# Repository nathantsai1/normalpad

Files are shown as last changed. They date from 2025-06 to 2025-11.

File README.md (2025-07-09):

# NormalPad

*Note: this is a hackboard, not a hackpad
## What is this?
This is a 75% keyboard inspired by the [Keychron Q1 Custom Keyboard](https://www.keychron.com/products/keychron-q1?srsltid=AfmBOorYcrgbMnQshTxcVkn31a3YPq6My79lAXlqjA35xHALWIpRg0Ld). It consists of 82 keys, hot-swappable switches a 3D printable case, and stabilizers. The bottom half is split in half to make it easier to sand

## Quick overview of repo
+ cad
    1. full_keyboard.stl
+ firmware
    1. normalPad.ino
+ pcb
    1. hackpad_v2.kicad_pcb
    2. hackpad_v2.kicad_prl
    3. hackpad_v2.kicad_pro
    4. hackpad_v2.kicad_sch
+ production
    + cad(stl)
        1. plate.stl
        2. upper_ex.stl
        3. bottom.stl
    1. normalPad.ino
    2. gerbers-zip.zip
+ src
    1. angle_bottom.png
    2. assembled_bottom.png
    3. bottom.png
    4. diagram.png
    5. pcb.png
    6. plate.png
    7. schem.png
    8. side_short.png
    9. side_long.png
    10. together.png
    11. top_plate.png
+ README.md
+ bom.csv
+ JOURNAL.md

*The more important files are contained in the production folder, README, and bom(in a ccsv file and at the end of this page)
## Why did I make this
I primarily started this for [HackPad v2](https://hackpad.hackclub.com/keyboard). However, during the process of making this, I learned more about the different types of switches, stabilizers, splitting up CAD designs into multiple parts, and all the parts of the keyboard. I learned a little bit more about the [Arduino Keyboard library](https://docs.arduino.cc/language-reference/en/functions/usb/Keyboard/), how to write relatively efficient code, and organize my pcb schematic and pcb in a larger scale than what I previously learned. As I had taken a break for a few months from my original keyboard design, I had stopped 

## Pictures of my design:
### Schematic:
<b>My diagram, which depicts the row and column numbers</b>

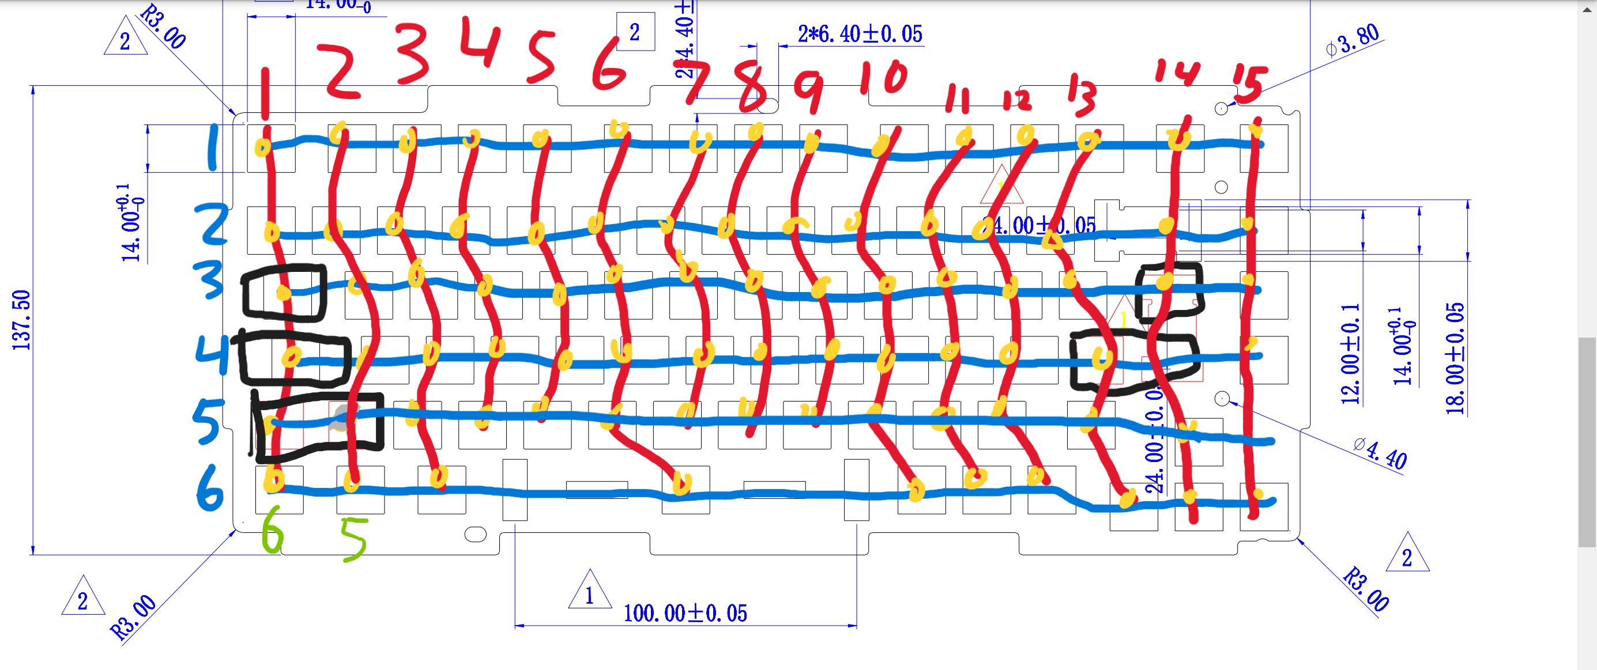
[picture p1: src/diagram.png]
diagram


<b>The schematic for the pcb, relatively organized in the order wanted</b>

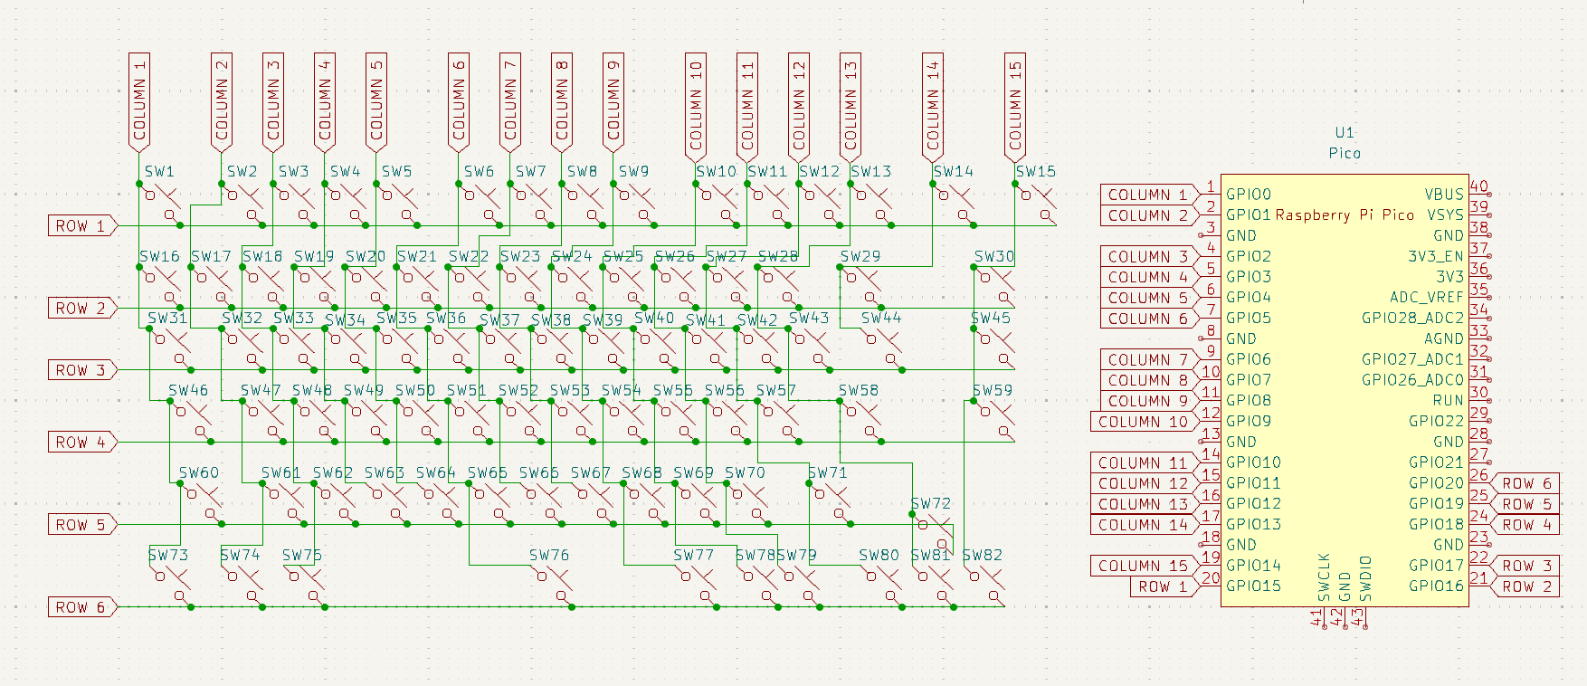
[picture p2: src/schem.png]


### PCB
<b>My PCB</b>

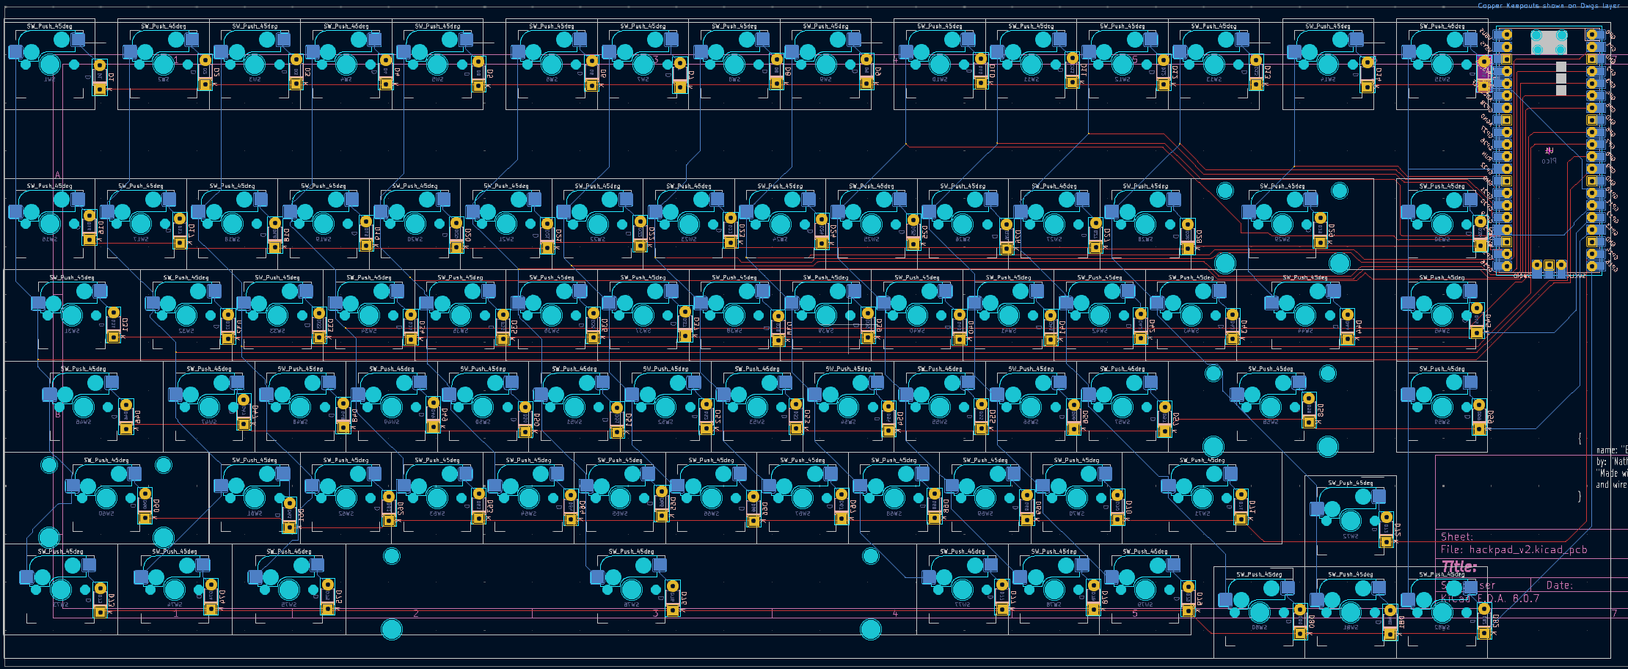
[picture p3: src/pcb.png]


<b>PCB back</b>

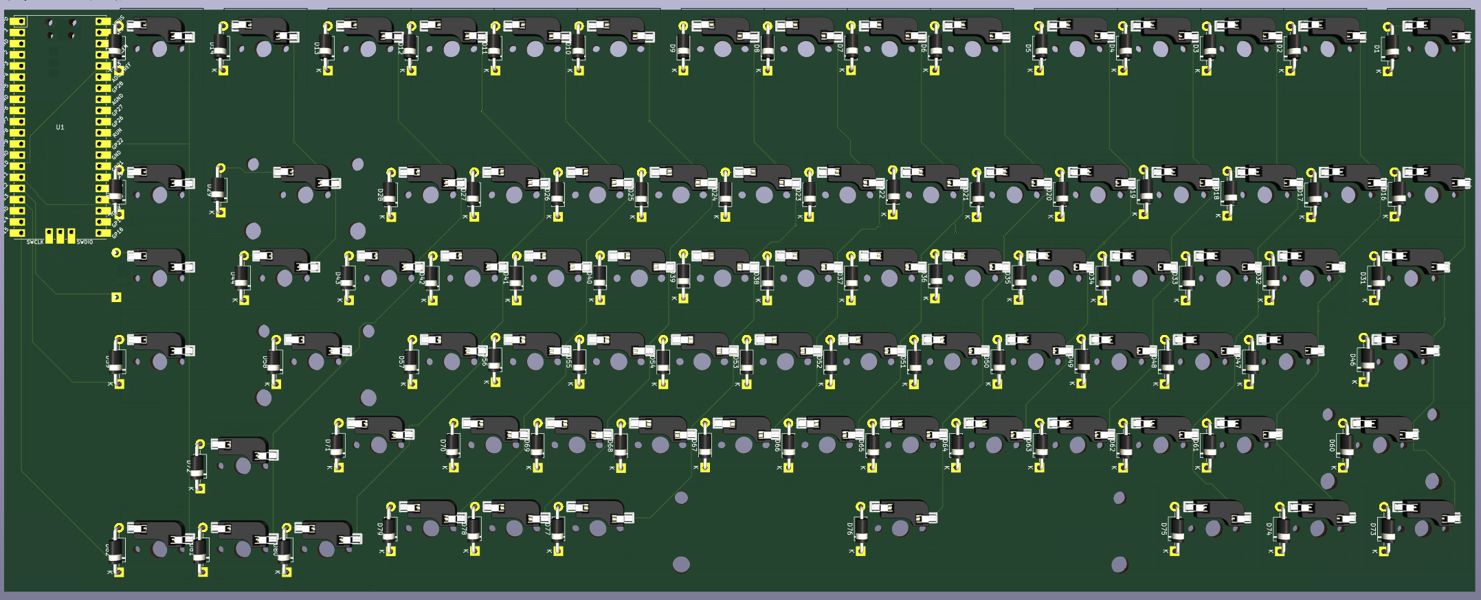
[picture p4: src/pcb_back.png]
pcb back


<b>PCB front (w/key switch side)</b>

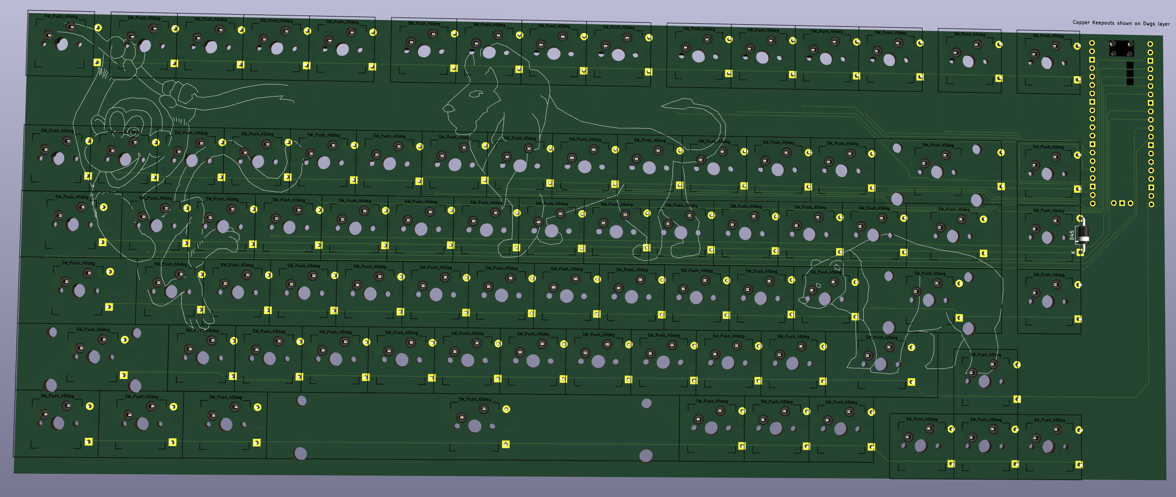
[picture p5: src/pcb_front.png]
pcb front


### CAD Case(Disassembled)
From top to bottom 

<b>Top plate</b>

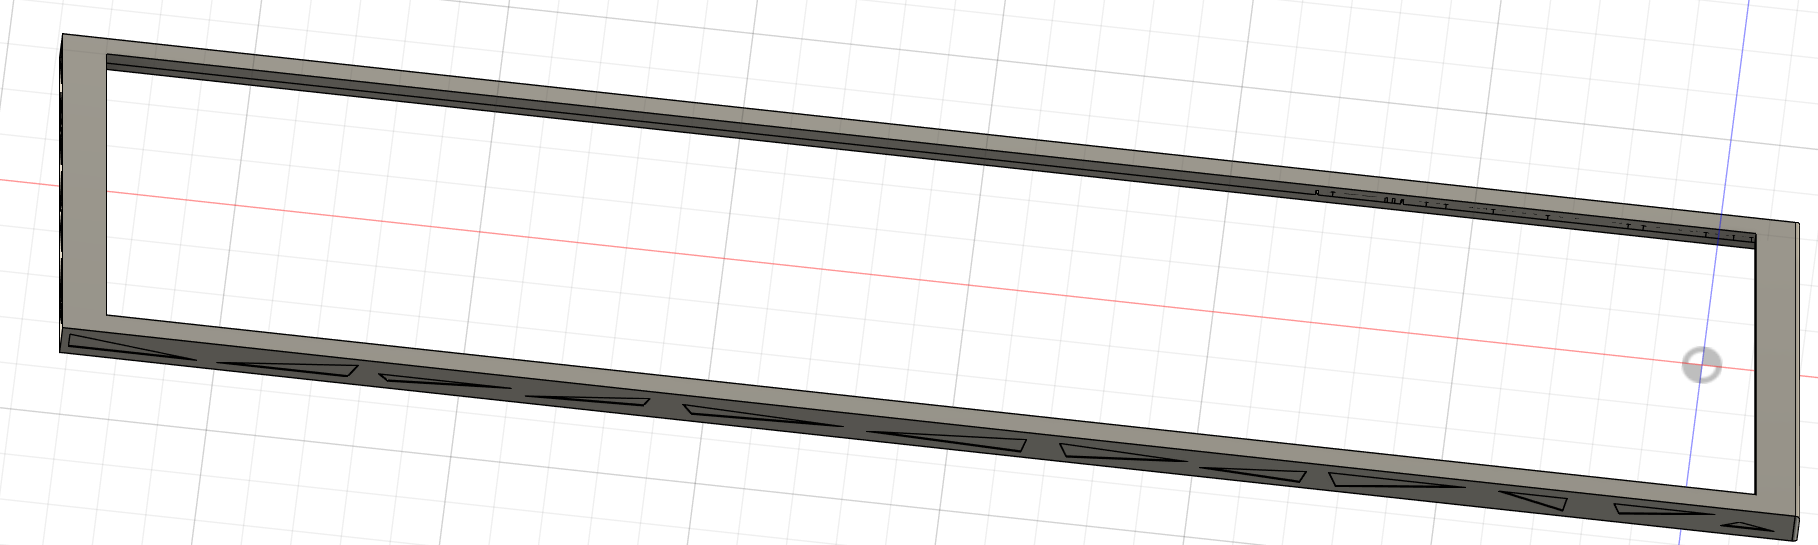
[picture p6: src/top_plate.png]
Top Plate


<b>Plate</b>

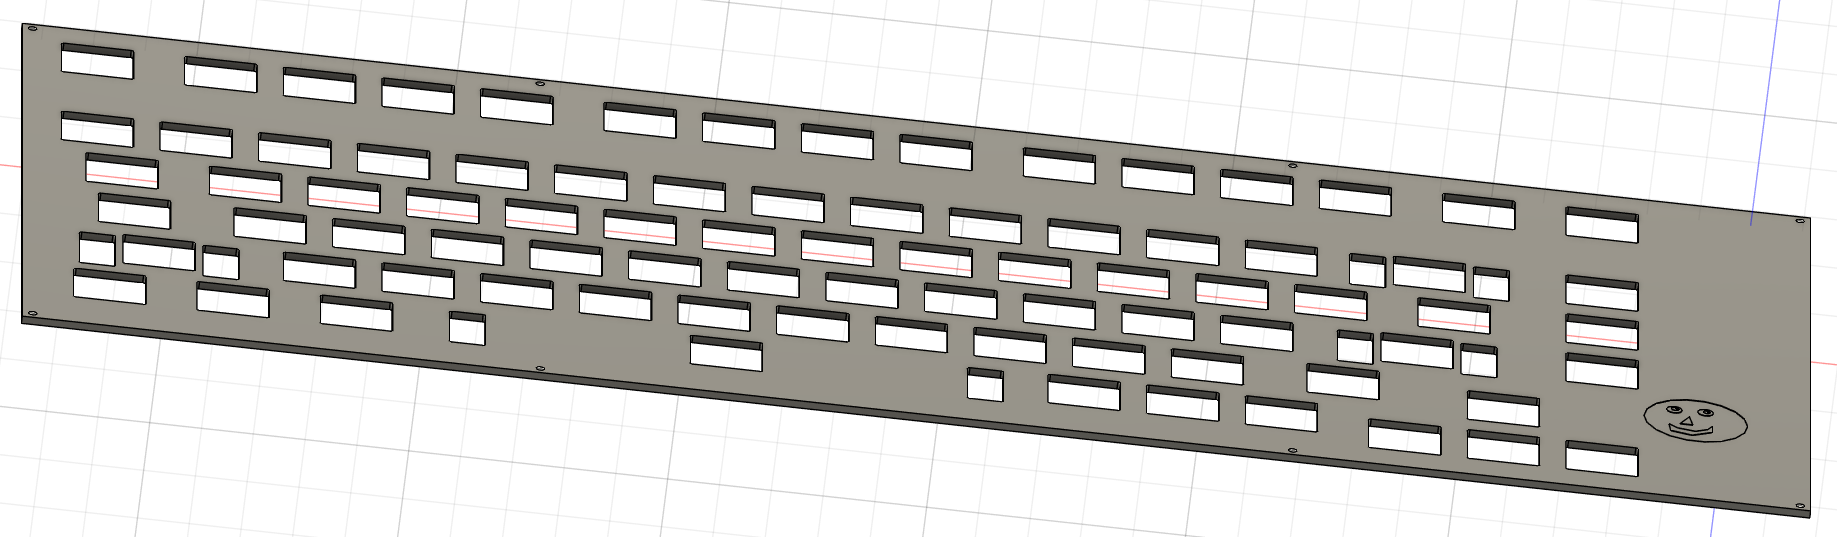
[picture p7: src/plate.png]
Plate


<b>Bottom</b>

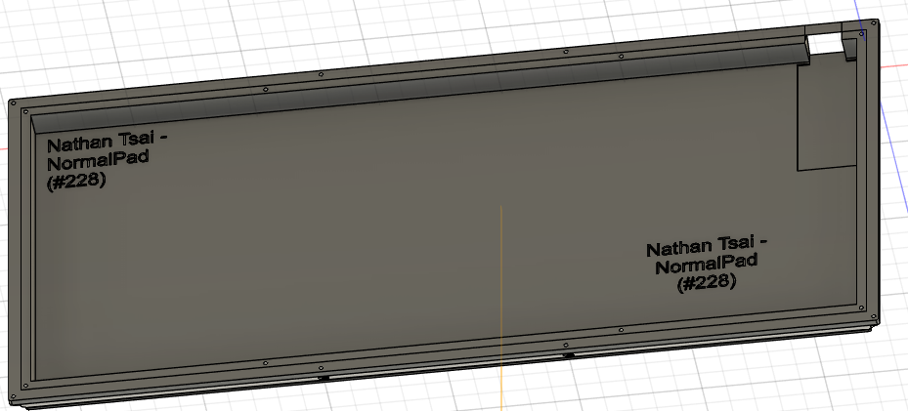
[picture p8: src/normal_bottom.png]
Bottom


### CAD case(relatively assembled)

<b>Assembled case</b>

Bottom assembled
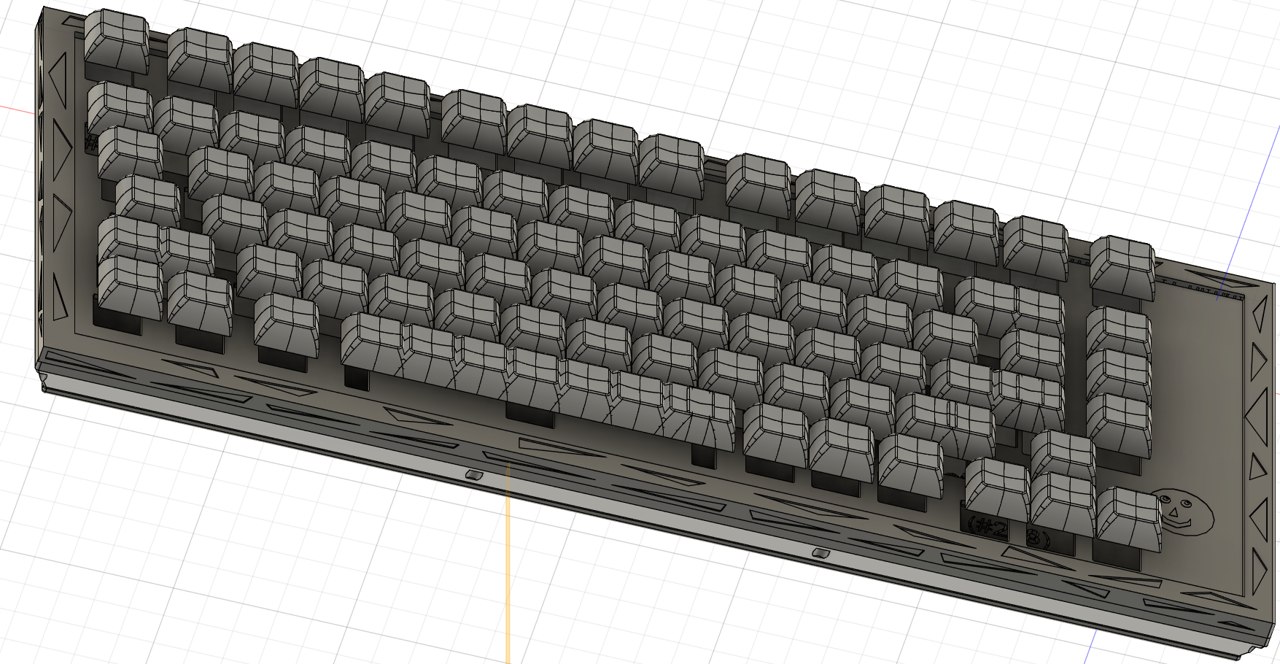
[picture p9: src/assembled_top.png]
Top assembled


<b>Side analysis of case</b>

side_long
side_short

<b>sketch of designsadded to project</b>
in order: back case, front case, front pcb

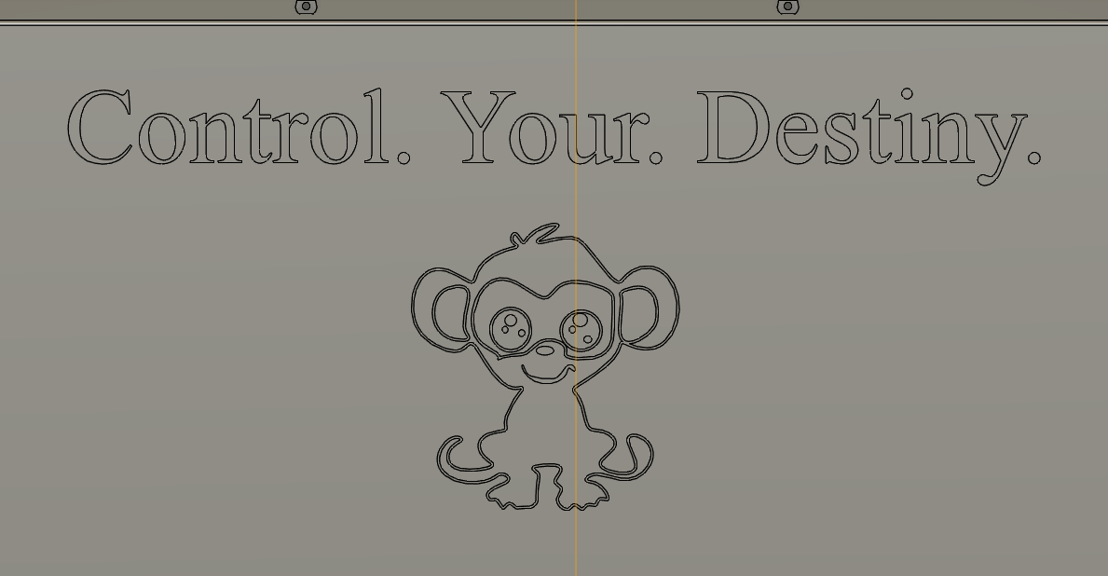
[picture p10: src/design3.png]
back_design

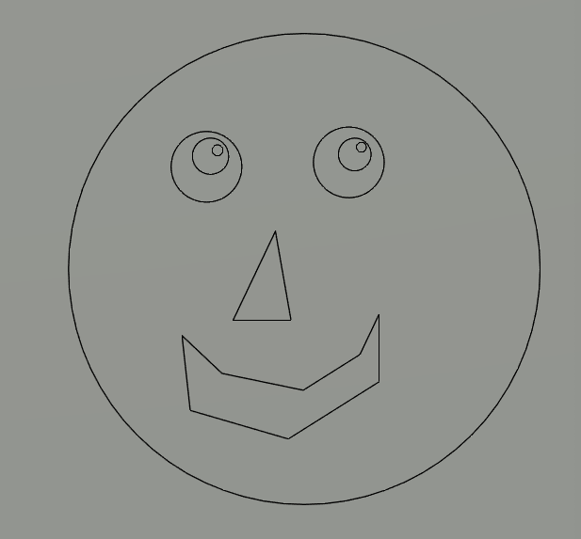
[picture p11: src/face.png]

back_design

## Bill of Materials
Also see [here](./BOM.csv)
|mfg name|	 Description|	 Price|	shipping|	total|	notes|
| ---| ---| ---| ---| ---| ---|
|ALIEXPRESS|	 [keycap set](https://www.aliexpress.us/item/3256803996370867.html)|	 9.23|	0|	 9.23| |
|ALIEXPRESS|	 [keyswitch(90)](https://www.aliexpress.us/item/3256807160745636.html)|	 25.17|	0|	 25.17| |
|ALIEXPRESS|	 taxes|	 0|	0|	 0| |
| | | | | | |
|JLCPCB|	 pcb|	 20.9|	17.13|	 38.03| |
| | | | | | |
|MECHANICAL KEYBOARD| [hot swap(90)](https://mechanicalkeyboards.com/products/kailh-switch-hot-swap-socket)|	 9.9| 	5.8|	 15.15| |
|MECHANIAL KEYBOARDS| [stabilizer](https://mechanicalkeyboards.com/products/durock-v3-pcb-mount-screw-in-stabilizer-tkl-kit)|	 15|	 6.27|	 21.27| |
| | | | | | |
|DIGIKEY|	 [Raspberry pi pico w/o header](https://www.digikey.com/en/products/detail/raspberry-pi/SC0915/13624793)|	 5|  	0|	 5| |
|DIGIKEY|	 [pin header 1x40](https://www.digikey.com/en/products/detail/amphenol-cs-commercial-products/G800W268018EU/17083164)|	 0.8|	|	 0.8| |
|DIGIKEY|	 [bolts(2Mx0.4 - 8mm*18)](https://www.digikey.com/en/products/detail/essentra-components/50M020040P008/11639927)|	1.76|	0|	 1.76| |
|DIGIKEY|	 [diode(84)](https://www.digikey.com/en/products/detail/comchip-technology/1N4001-G/1979654)|	 4.54|	0|	 4.54| |
|DIGIKEY|	 total(tariff+tax, shipping)|	 1.57|	4.99|	 6.56| |
|CAD CASE|	 cad case|	 |	|	 5.51| |
Total (with case and PCB): 133.02
Total (without case and PCB) 89.48
*PRICES IN USD

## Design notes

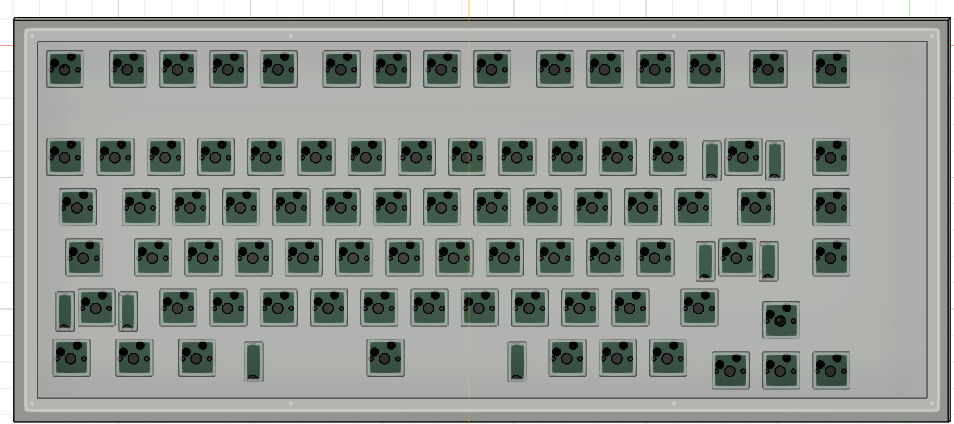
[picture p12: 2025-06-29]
src/pcb_fit.png

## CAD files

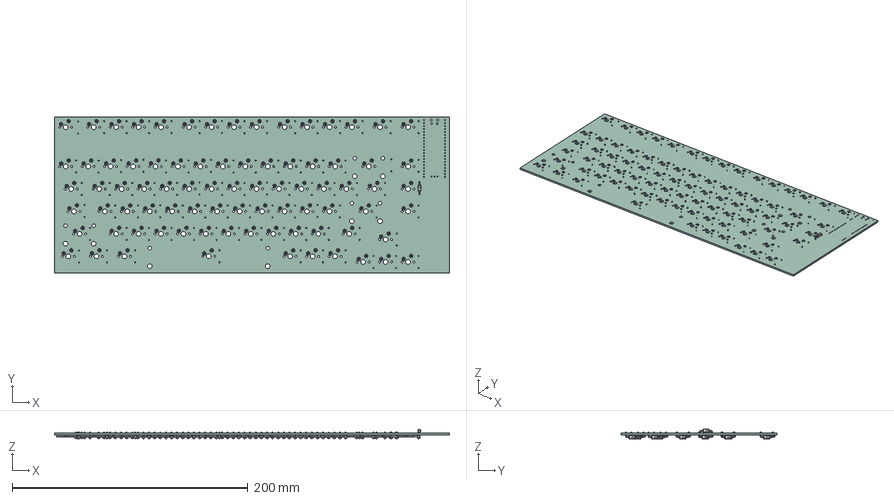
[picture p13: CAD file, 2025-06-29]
cad/pcb.step
335.0 x 132.7 x 8.12 mm
D_DO-41_SOD81_P10.16mm_Horizontal x 82
Kailh Socket v12 x 82
hackpad_v2_PCB

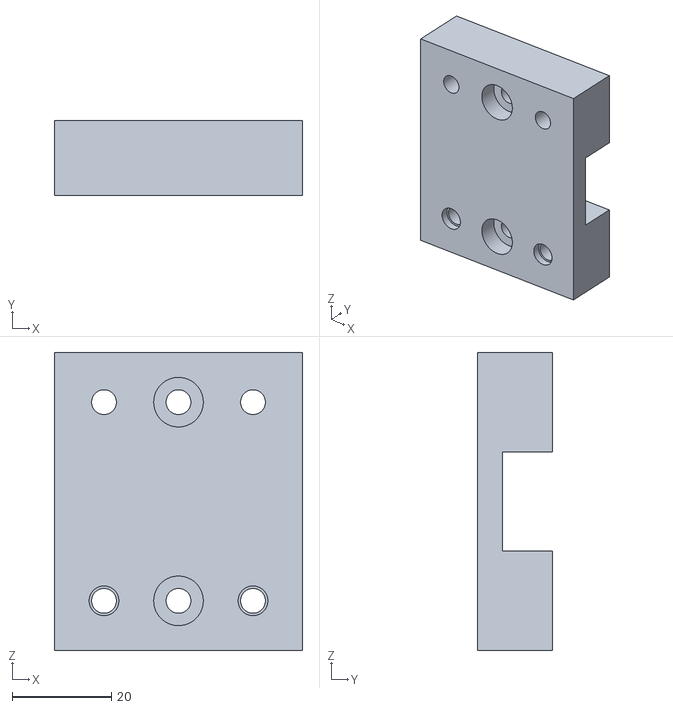
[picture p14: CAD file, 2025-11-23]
production/cad(stl)/undercity v3.stl
50.0 x 15.0 x 60.0

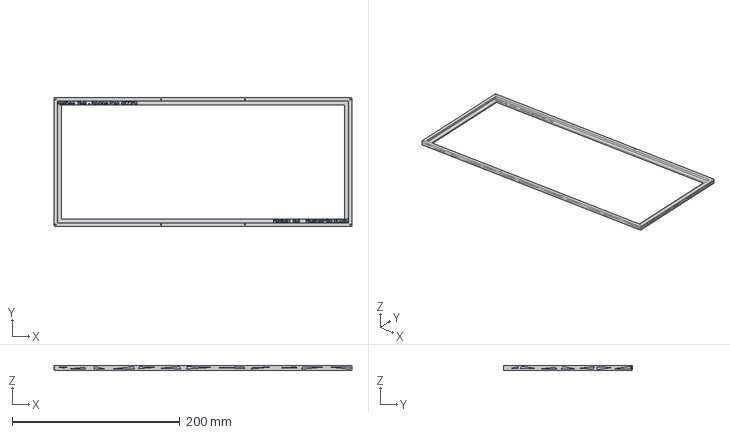
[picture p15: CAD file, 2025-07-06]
production/cad(stl)/upper_ex.step
355.3 x 153.3 x 5.50 mm

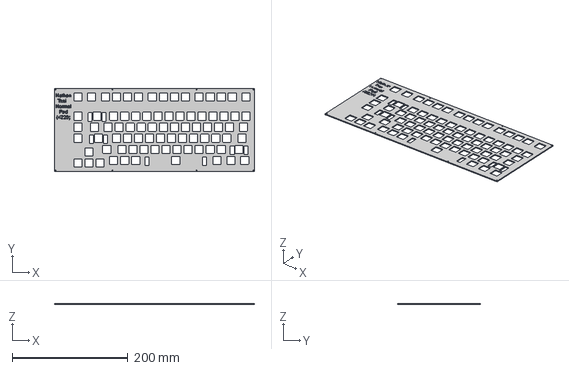
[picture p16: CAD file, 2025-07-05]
production/cad(stl)/plate.step
345.3 x 143.4 x 1.50 mm

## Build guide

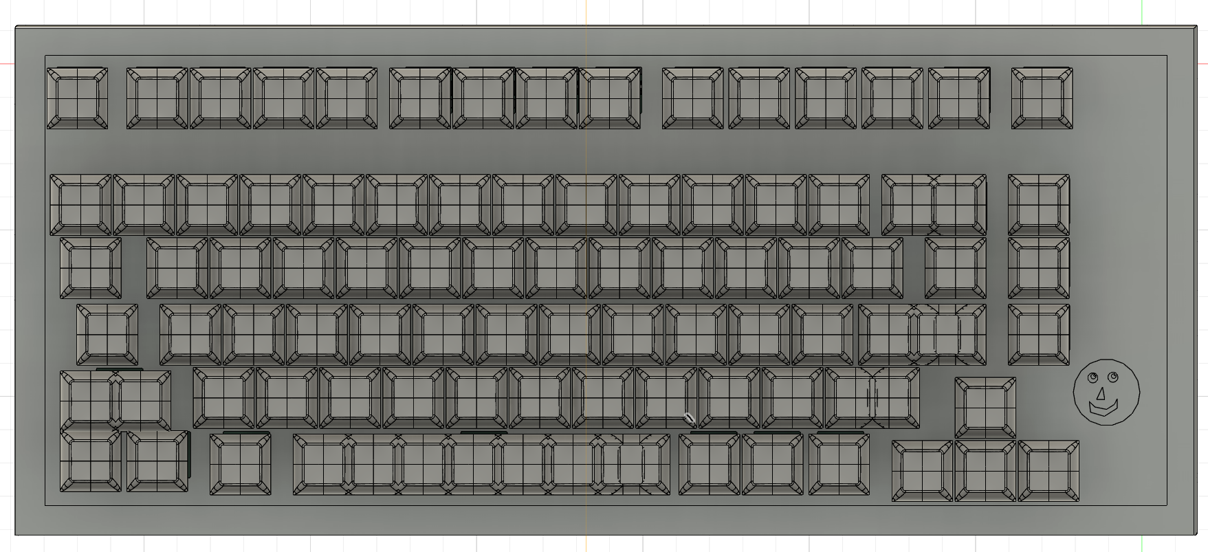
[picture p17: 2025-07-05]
src/assembledtop.png

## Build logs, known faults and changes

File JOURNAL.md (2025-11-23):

---
title: "NormalPad"
author: "Nathan Tsai"
description: "A 75% Keyboard w/82 silent tactile switches"
created_at: "2024-12-24"
---

| title | Author | description | created_at |
|--|--|--|--|
| NormalPad | Nathan Tsai | A 75% Keyboard w/82 Silent tactile switches | 2024-12-24|

Time spent: ~30-40 hours total

*Note: Although I started this project for Hackpad v2, I never got around to finishing it until recently. At this point, I had finished the main CAD, a relatively finished BOM and main PCB, which probably took around 20-30 hours of time - I redid the CAD case 2-3 times, as I didn't like the design structure and it didn't fit the pcb, and the PCB layout took a while since I rewired the copper multiple times. 

*Another note: I didn't keep good track of my time while creating my project, so it might be very inaccurate.

## June 24th: Checking PCB
Since I had finished my PCB, I thought about checking the PCB to make sure each part fit. I checked the BOM, and realized that although the Kailh hot swap keys and stabilizers seemed to fit, the diodes were the wrong size. Apperantly I had used D-35 7.62mm resister footprint but I wanted to buy D-41 10.16mm as they came in for a relatively good price($5 for 100pc at Amazon). Thus I found the right footprint after spending a lot of time trying to match the 7.62mm diode, and exploring SMD options to assemble at JLCPCB instead of soldering it myself. Eventually I realized that this was a waste of time, as I could have taken a different footprint - the D-41 10.16mm one, which I found after searching the Kicad library multiple times. 

Time: ~2 Hours

<b>One switch but this process with 82 keys instead of one as pictured here</b>
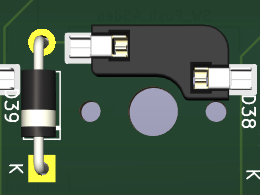
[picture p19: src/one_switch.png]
one switch


## June 25th: Checking validation between whole project
Since I had finished my project, I wanted to make sure that the whole project was going to be ok. First, I checked the CAD design. I realized that there weren't any supports, so i added a 0.4mm unstable support for the bottoms of the cad case that hopefully doesn't fall apart during printing for the case - fingers crossed! Then I checked the BOM for anything that seemed off. There didn't seem to be anything off, but I was really confused about how the shipping worked. Time to take a break!

Time: ~2-3 Hours

<b>the supports</b> - Basically I split the bottom keyboard in half to make it easier to find people who could print the full size keyboard
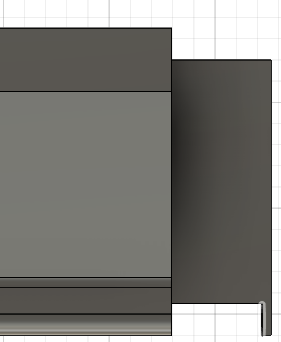
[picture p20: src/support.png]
bottom_left


## June 26th: Frantically checking shipping prices
I had forgot about CAD shipping until yesterday. I haven't used USPS before, but I checked their website to see how much shipping would cost. It took a while to find their Priority Mail page where I found it would cost around $10.75 for shipping. I'm still hesitant on that number, though, as the package could be bigger than expected or the mail people might upcharge. Otherwise, it should be fine. The most annoying part, though, was trying to convert the keyboard dimensions from mm to inches, where I used a number converter. I kept forgetting the numbers as there were too many and I guessed some of them(4 - length, width, height, and weight)

Trying to sift through a bunch of words I don't understand. I figured out what the zones meant though, and that my package might cost more than the average CAD design.
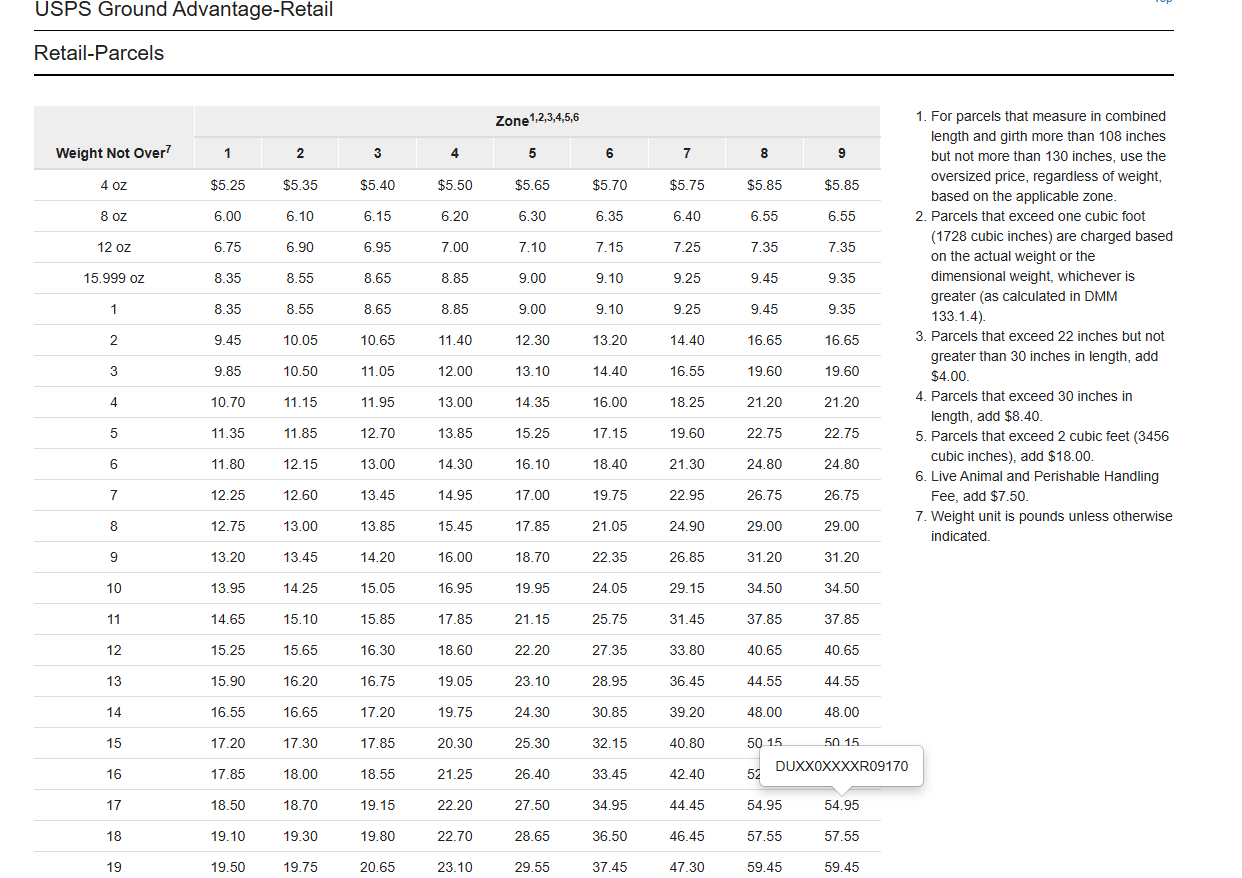
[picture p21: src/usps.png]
usps

Time ~1-2 hours

## June 27th: Finishing up project
I realized that my split bottom was more of a hassle than an asset, so I spent some time combining it. I also finished the README, taking a lot of pictures, which was kind of annoying.

Time: ~1-2 hours

The amount of pictures I added to the README(excluding ~5 pictures)

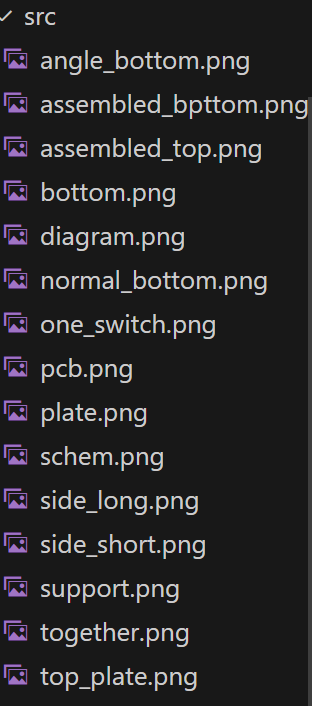
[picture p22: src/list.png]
list


*Sidenote: My computer insisted upon deleting random files, and Onedrive complained that I should upload my precious files into its tiny 5 GB cloud storage. I clicked ok, and now my files are messed up :(

## June 28th: Billing issues
Originally, I had planned to get a lot of parts from Amazon as the prices were actually and looked more reliable than Aliexpress. However, I had seen that they had charged me $20 in unknown price fees, shipping not included. I took a while trying to source parts from different sources than Amazon, which actually was annoying as I wanted to lower the price but keep the quality of my products. Sadly, I took out my durock silent t1 shrimps key switch from the BOM to lower the overall cost. The switches and stabilizers went from MechanicalKeyboards to Milktooth to Aliexpress and a few more. I wasn't happy with Amazon, as they hid their end prices(price with tax and shipping), so nothing on the BOM is from them. 

I added the keycaps to show the final project, which took a lot of time
final project
Other than that, I checked the Highway submission guidelines and cleaned up the project

Time: 3-5 hours

## July 1st: fixing problems
I changed the bottom cad design, the BOM and added the pcb step files to the cad folder
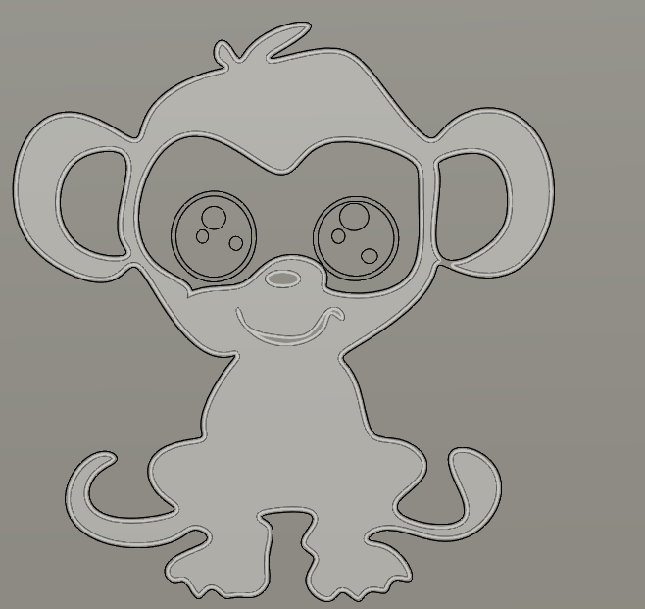
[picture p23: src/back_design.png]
monkey design

Time: 1-2 hours

## July 5: fix problems
added more designs
monkey design
monkey design

## July 8th: Ordering parts
I started ordering parts. However, I realized that the stabilizers were more expensive than previously though and so I had to change both the stabilizers and the store as the one I had in mind was sold out on the original website and also more expensive on every single other. 
While ordering my stabilizers, the order was reversed. 3 times. I ended up ordering the Durock stabilizers from Mechanical Keyboards.
I also updated the BOMs for more accuracy
Time: 2-4 hours

## 11/22/25: everything but sped up
I forgot to log for the past few months bc everything was really slow. I got all the parts, but realized the hole in the case wasn't the size I wanted. I tried to get some screws from Aliexpress (never arrived) and now am wondering whether I should get 50 from Digikey rn. 
I also soldered everything together, which was a pain. I soldered some in the wrong directin, and one of them wasn't soldered.
The software came along nicely, so the keyboard registers a click and can assign it the right letter. I haven't put on the keycaps yet. I had to use anthropic to debug that I was using high/low pins and not input_pullup/input / output, and switched the rows and columns.
Overall, I'm happy to see how this turned out, my CAD design looks finished, and that it seems like a good build to build. 
Time:12-24 hours

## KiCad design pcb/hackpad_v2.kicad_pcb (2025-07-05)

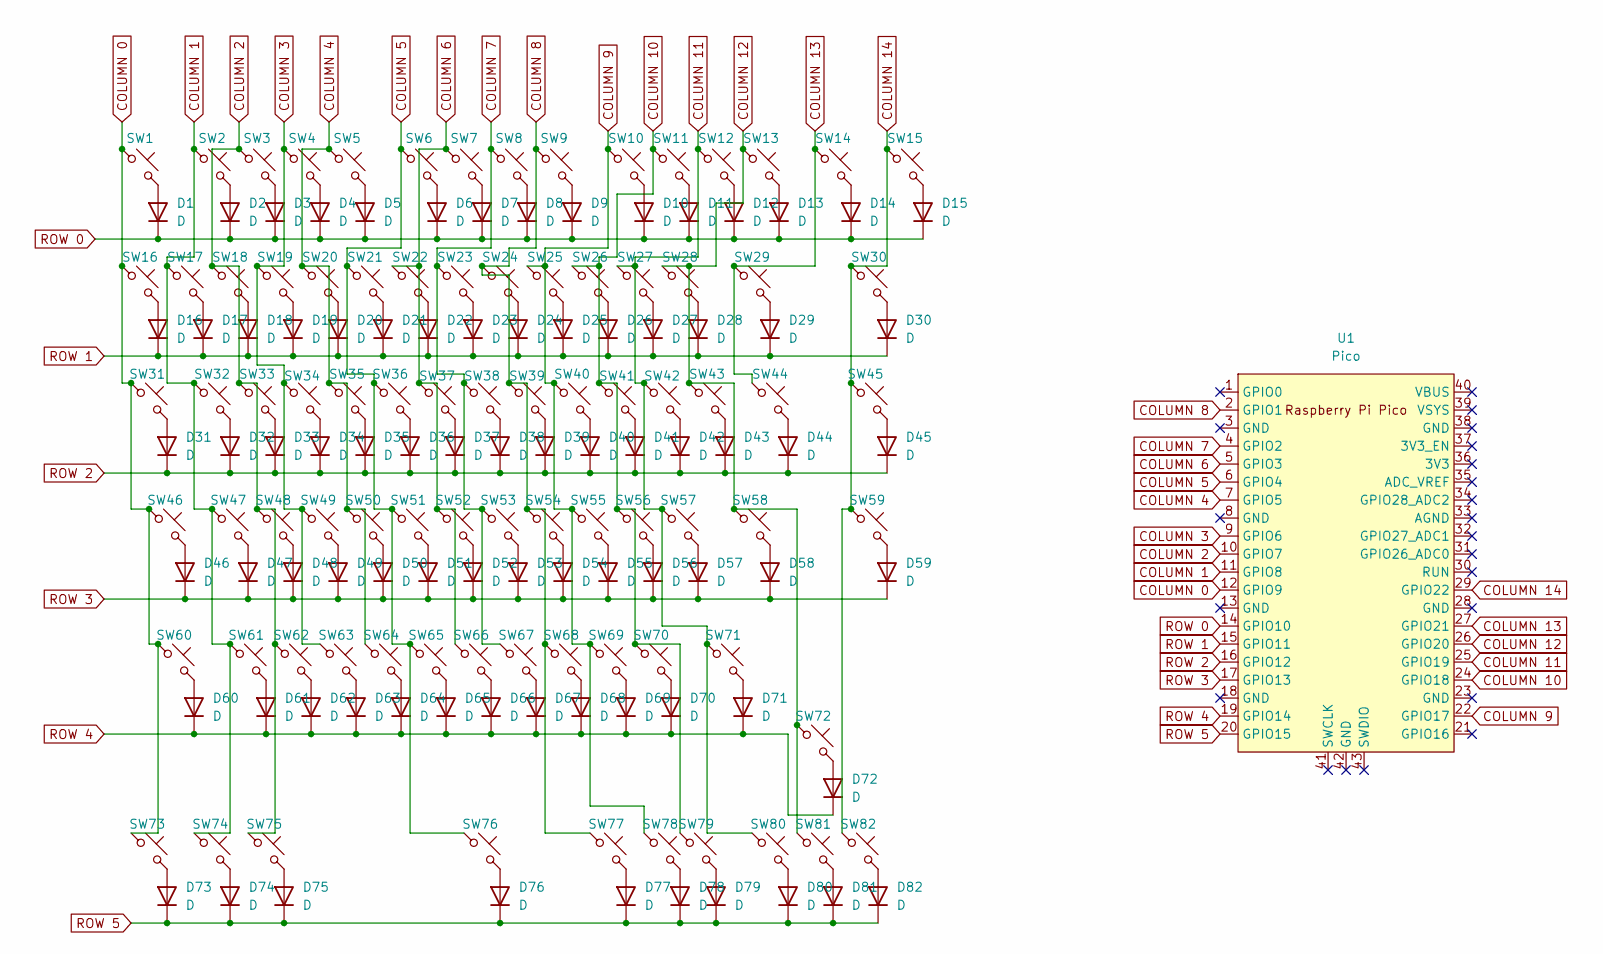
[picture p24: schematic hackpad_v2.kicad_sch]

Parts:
D1, D2, D3, D4, D5, D6, D7, D8, D9, D10, D11, D12, D13, D14, D15, D16, D17, D18, D19, D20, D21, D22, D23, D24, D25, D26, D27, D28, D29, D30, D31, D32, D33, D34, D35, D36, D37, D38, D39, D40, D41, D42, D43, D44, D45, D46, D47, D48, D49, D50, D51, D52, D53, D54, D55, D56, D57, D58, D59, D60, D61, D62, D63, D64, D65, D66, D67, D68, D69, D70, D71, D72, D73, D74, D75, D76, D77, D78, D79, D80, D81, D82: D; D_DO-41_SOD81_P10.16mm_Horizontal
SW1, SW2, SW3, SW4, SW5, SW6, SW7, SW8, SW9, SW10, SW11, SW12, SW13, SW14, SW15, SW16, SW17, SW18, SW19, SW20, SW21, SW22, SW23, SW24, SW25, SW26, SW27, SW28, SW30, SW32, SW33, SW34, SW35, SW36, SW37, SW38, SW39, SW40, SW41, SW42, SW43, SW45, SW47, SW48, SW49, SW50, SW51, SW52, SW53, SW54, SW55, SW56, SW57, SW59, SW61, SW62, SW63, SW64, SW65, SW66, SW67, SW68, SW69, SW70, SW72, SW77, SW78, SW79, SW80, SW81, SW82: SW_Push_45deg; MX-Hotswap-1U
SW29: SW_Push_45deg; MX-Hotswap-2U
SW31, SW44: SW_Push_45deg; MX-Hotswap-1.5U
SW46, SW71: SW_Push_45deg; MX-Hotswap-1.75U
SW58, SW60: SW_Push_45deg; MX-Hotswap-2.25U
SW73, SW74, SW75: SW_Push_45deg; MX-Hotswap-1.25U
SW76: SW_Push_45deg; MX-Hotswap-6.25U
U1: Pico; RPi_Pico_SMD_TH

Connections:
COLUMN 0: SW1.1, SW16.1, SW31.1, SW46.1, SW60.1, SW73.1, U1.12 (GPIO9)
COLUMN 1: SW2.1, SW17.1, SW32.1, SW47.1, SW61.1, SW74.1, U1.11 (GPIO8)
COLUMN 2: SW3.1, SW18.1, SW33.1, SW48.1, SW62.1, SW75.1, U1.10 (GPIO7)
COLUMN 3: SW4.1, SW19.1, SW34.1, SW49.1, SW63.1, U1.9 (GPIO6)
COLUMN 4: SW5.1, SW20.1, SW35.1, SW50.1, SW64.1, U1.7 (GPIO5)
COLUMN 5: SW6.1, SW21.1, SW36.1, SW51.1, SW65.1, SW76.1, U1.6 (GPIO4)
COLUMN 6: SW7.1, SW22.1, SW37.1, SW52.1, SW66.1, U1.5 (GPIO3)
COLUMN 7: SW8.1, SW23.1, SW38.1, SW53.1, SW67.1, U1.4 (GPIO2)
COLUMN 8: SW9.1, SW24.1, SW39.1, SW54.1, SW68.1, SW77.1, U1.2 (GPIO1)
COLUMN 9: SW10.1, SW25.1, SW40.1, SW55.1, SW69.1, SW78.1, U1.22 (GPIO17)
COLUMN 10: SW11.1, SW26.1, SW41.1, SW56.1, SW70.1, SW79.1, U1.24 (GPIO18)
COLUMN 11: SW12.1, SW27.1, SW42.1, SW57.1, SW71.1, SW80.1, U1.25 (GPIO19)
COLUMN 12: SW13.1, SW28.1, SW43.1, SW58.1, SW72.1, SW81.1, U1.26 (GPIO20)
COLUMN 13: SW14.1, SW29.1, SW44.1, U1.27 (GPIO21)
COLUMN 14: SW15.1, SW30.1, SW45.1, SW59.1, SW82.1, U1.29 (GPIO22)
unnamed: D1.2 (A), SW1.2
unnamed: D2.2 (A), SW2.2
unnamed: D3.2 (A), SW3.2
unnamed: D4.2 (A), SW4.2
unnamed: D5.2 (A), SW5.2
unnamed: D6.2 (A), SW6.2
unnamed: D7.2 (A), SW7.2
unnamed: D8.2 (A), SW8.2
unnamed: D9.2 (A), SW9.2
unnamed: D10.2 (A), SW10.2
unnamed: D11.2 (A), SW11.2
unnamed: D12.2 (A), SW12.2
unnamed: D13.2 (A), SW13.2
unnamed: D14.2 (A), SW14.2
unnamed: D15.2 (A), SW15.2
unnamed: D16.2 (A), SW16.2
unnamed: D17.2 (A), SW17.2
unnamed: D18.2 (A), SW18.2
unnamed: D19.2 (A), SW19.2
unnamed: D20.2 (A), SW20.2
unnamed: D21.2 (A), SW21.2
unnamed: D22.2 (A), SW22.2
unnamed: D23.2 (A), SW23.2
unnamed: D24.2 (A), SW24.2
unnamed: D25.2 (A), SW25.2
unnamed: D26.2 (A), SW26.2
unnamed: D27.2 (A), SW27.2
unnamed: D28.2 (A), SW28.2
unnamed: D29.2 (A), SW29.2
unnamed: D30.2 (A), SW30.2
unnamed: D31.2 (A), SW31.2
unnamed: D32.2 (A), SW32.2
unnamed: D33.2 (A), SW33.2
unnamed: D34.2 (A), SW34.2
unnamed: D35.2 (A), SW35.2
unnamed: D36.2 (A), SW36.2
unnamed: D37.2 (A), SW37.2
unnamed: D38.2 (A), SW38.2
unnamed: D39.2 (A), SW39.2
unnamed: D40.2 (A), SW40.2
unnamed: D41.2 (A), SW41.2
unnamed: D42.2 (A), SW42.2
unnamed: D43.2 (A), SW43.2
unnamed: D44.2 (A), SW44.2
unnamed: D45.2 (A), SW45.2
unnamed: D46.2 (A), SW46.2
unnamed: D47.2 (A), SW47.2
unnamed: D48.2 (A), SW48.2
unnamed: D49.2 (A), SW49.2
unnamed: D50.2 (A), SW50.2
unnamed: D51.2 (A), SW51.2
unnamed: D52.2 (A), SW52.2
unnamed: D53.2 (A), SW53.2
unnamed: D54.2 (A), SW54.2
unnamed: D55.2 (A), SW55.2
unnamed: D56.2 (A), SW56.2
unnamed: D57.2 (A), SW57.2
unnamed: D58.2 (A), SW58.2
unnamed: D59.2 (A), SW59.2
unnamed: D60.2 (A), SW60.2
unnamed: D61.2 (A), SW61.2
unnamed: D62.2 (A), SW62.2
unnamed: D63.2 (A), SW63.2
unnamed: D64.2 (A), SW64.2
unnamed: D65.2 (A), SW65.2
unnamed: D66.2 (A), SW66.2
unnamed: D67.2 (A), SW67.2
unnamed: D68.2 (A), SW68.2
unnamed: D69.2 (A), SW69.2
unnamed: D70.2 (A), SW70.2
unnamed: D71.2 (A), SW71.2
unnamed: D72.2 (A), SW72.2
unnamed: D73.2 (A), SW73.2
unnamed: D74.2 (A), SW74.2
unnamed: D75.2 (A), SW75.2
unnamed: D76.2 (A), SW76.2
unnamed: D77.2 (A), SW77.2
unnamed: D78.2 (A), SW78.2
unnamed: D79.2 (A), SW79.2
unnamed: D80.2 (A), SW80.2
unnamed: D81.2 (A), SW81.2
unnamed: D82.2 (A), SW82.2
ROW 0: D1.1 (K), D2.1 (K), D3.1 (K), D4.1 (K), D5.1 (K), D6.1 (K), D7.1 (K), D8.1 (K), D9.1 (K), D10.1 (K), D11.1 (K), D12.1 (K), D13.1 (K), D14.1 (K), D15.1 (K), U1.14 (GPIO10)
ROW 1: D16.1 (K), D17.1 (K), D18.1 (K), D19.1 (K), D20.1 (K), D21.1 (K), D22.1 (K), D23.1 (K), D24.1 (K), D25.1 (K), D26.1 (K), D27.1 (K), D28.1 (K), D29.1 (K), D30.1 (K), U1.15 (GPIO11)
ROW 2: D31.1 (K), D32.1 (K), D33.1 (K), D34.1 (K), D35.1 (K), D36.1 (K), D37.1 (K), D38.1 (K), D39.1 (K), D40.1 (K), D41.1 (K), D42.1 (K), D43.1 (K), D44.1 (K), D45.1 (K), U1.16 (GPIO12)
ROW 3: D46.1 (K), D47.1 (K), D48.1 (K), D49.1 (K), D50.1 (K), D51.1 (K), D52.1 (K), D53.1 (K), D54.1 (K), D55.1 (K), D56.1 (K), D57.1 (K), D58.1 (K), D59.1 (K), U1.17 (GPIO13)
ROW 4: D60.1 (K), D61.1 (K), D62.1 (K), D63.1 (K), D64.1 (K), D65.1 (K), D66.1 (K), D67.1 (K), D68.1 (K), D69.1 (K), D70.1 (K), D71.1 (K), D72.1 (K), U1.19 (GPIO14)
ROW 5: D73.1 (K), D74.1 (K), D75.1 (K), D76.1 (K), D77.1 (K), D78.1 (K), D79.1 (K), D80.1 (K), D81.1 (K), D82.1 (K), U1.20 (GPIO15)

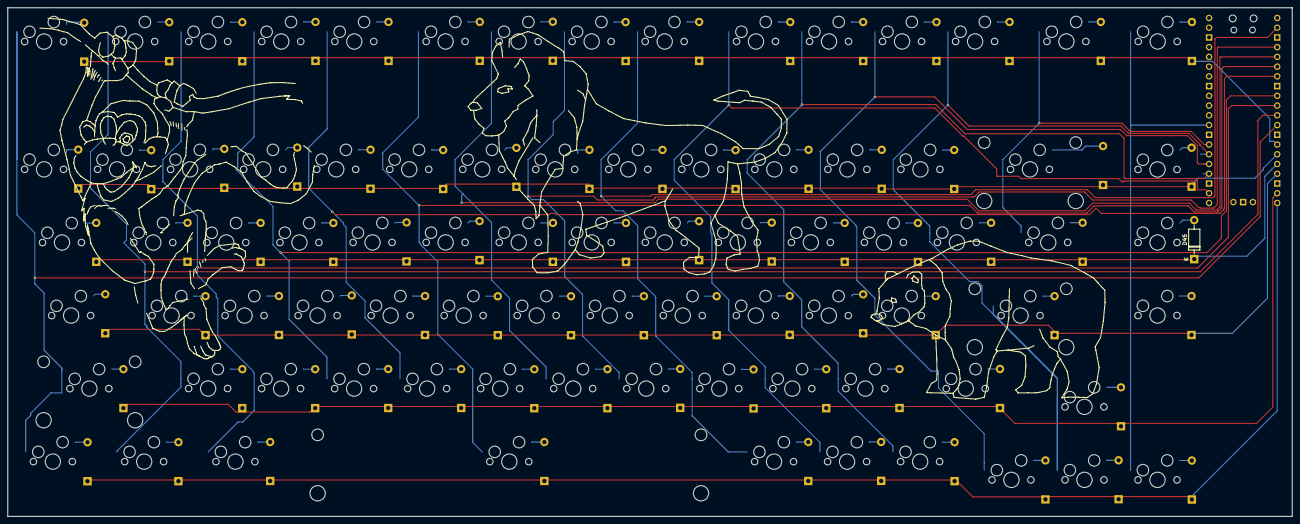
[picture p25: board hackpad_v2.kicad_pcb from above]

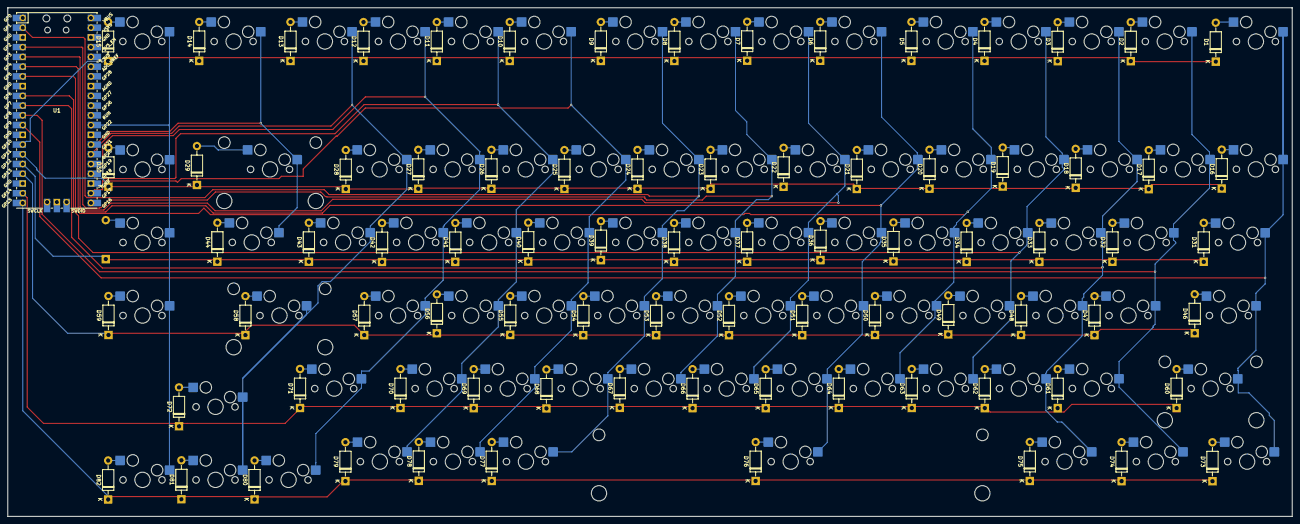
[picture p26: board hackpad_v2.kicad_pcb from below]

Board: 2 copper layers, 335.0 x 132.7 mm, 165 parts (164 on the bottom side), 103 nets.

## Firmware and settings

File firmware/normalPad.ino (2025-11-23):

#include <Keyboard.h>

int val;

/* this is the code for a keyboard - see the github file for schematics
it uses the rows as input and columns as output
as you can see, i set the schematic to do something really weird
I used Arduino bc Arduino > Micropython 
Sticky Keys are turned on by default. I'm too lazy to change that 
Inspired by Keychron q1 custom keyboard
It only works theoretically */

// set amount of rows/columns
#define ROWS 6
#define COLUMNS 15
#define DEEPSLEEP 10000 // when to deep/light sleep in ms
#define DEEPSLEEPWHEN 60000
#define LIGHTSLEEP 2000
#define LIGHTSLEEPWHEN 10000

// set column and row pins(bc they're irregular)
int row_pins[ROWS] = { 10, 11, 12, 13, 14, 15 };
int column_pins[COLUMNS] = { 9, 8, 7, 6, 5, 4, 3, 2, 1, 17, 18, 19, 20, 21, 22 };

// set lower alphabet(type[column][row]) - assuming that shift will automatically be called
// 0 represents a blank space
int alphabet[ROWS][COLUMNS] = {
  { 177,  194,  195,  196,  197,  198,  199,  200,  201,  202,  203,  204,  205,  212,  209  },
  { 96,   '1',  '2',  '3',  '4',  '5',  '6',  '7',  '8',  '9',  '0',  45,   61,   178,  211  },
  { 179,  'q',  'w',  'e',  'r',  't',  'y',  'u',  'i',  'o',  'p',  91,   93,   92,   214  },
  { 193,  'a',  's',  'd',  'f',  'g',  'h',  'j',  'k',  'l',  59,   39,   '\n', 0,    210  },
  { 129,  'z',  'x',  'c',  'v',  'b',  'n',  'm',  44,   46,   47,   133,  218,  0,    0    },
  { 128,  130,  131,  0,    0,    32,   0,    0,    135,  0,    132,  216,  217,  0,    215  }
};

// set which row the output is on, whether shift and control and windows is on
int iteration_count = 0;
bool is_shift = false;
bool is_ctrl = false;
bool is_gui = false;
bool is_alt = false;

int specialKeyIsPressed[4][3] = {
  {0, 129, false}, // 0=is_shift, 129=keyToPress, 0=isPressed?
  {1, 128, false},
  {2, 131, false},
  {3, 135, false}
};
// when was keypress last "registered"
unsigned long lastKeyPress = millis(); 
unsigned long calculateKeyPress;
bool isKeyPressedDown = false;


// helper functions ; skip to main stuff
void doWhenKeyIsPressed(int x, int y) {
  val = digitalRead(column_pins[x]); // is column x connected when row y is on? Button thus pressed
  if (val == 0) {
    Serial.print("Key pressed: "); // beta beta
    Serial.print(x); // beta beta
    Serial.print(','); // beta beta
    Serial.print(y); // beta beta
    Serial.print(','); // beta beta
    Serial.println(alphabet[y][x]); // beta beta
    is_shift = ((x == 0 && y == 4) || (x == 11 && y == 4));  // shift key
    is_ctrl = ((x == 0 && y == 5) || (x == 11 && y == 5));   // ctrl key
    is_gui = ((x == 2 && y == 5) || (x == 9 && y == 5));     // windows key
    is_alt = ((x == 8 && y == 5) || (x == 1 && y == 5)); // alt key

    if ()
    if (!isShiftPressed && !isCtrlPressed && !isGuiPressed && !is_alt) {

    }
    // if (!is_shift && !is_ctrl && !is_gui && !is_alt) {
    //   Keyboard.write(alphabet[y][x]); // wierd i know but counts rows before columns
    //   Keyboard.releaseAll();
    //   isKeyPressedDown = false;
    // }
    // else {
    //   isKeyPressedDown = true;
    //   Keyboard.press(alphabet[y][x]); // sticky keys :) too much work to implement differently
    // }

    lastKeyPress = millis(); // reset keyboard sleepyness
  }
}

void shouldKeyboardSleep() { // sleep NOT power saving :)
  calculateKeyPress = millis() - lastKeyPress;
  if (calculateKeyPress > DEEPSLEEPWHEN) {
    delay(DEEPSLEEP);
  } else if (calculateKeyPress > LIGHTSLEEPWHEN) {
    delay(LIGHTSLEEP);
  }
}

void turnOffKeysIfNeeded() { // for fancy keyboard.press stuff
  if (isKeyPressedDown == true && (lastKeyPress - millis() > 3000)) { // if key pressed for long time...
    Keyboard.releaseAll();
    isKeyPressedDown = false;
  }
}



// main stuff
void setup() {
  Serial.begin(9600);
  Serial.println("Starting Keyboard..."); // beta beta

  // set rows as input - takes power
  for (int i = 0; i < ROWS; i++) {
    pinMode(row_pins[i], OUTPUT);
    digitalWrite(row_pins[i], HIGH);
  }

  // set columns as output - gives power
  for (int i = 0; i < COLUMNS; i++) {
    pinMode(column_pins[i], INPUT_PULLUP); // input w/pullup
  }

  Keyboard.begin();
}

void loop() {
  // very simple loop - iterate thorugh x then y coords and check if there is output
  for (int y = 0; y < ROWS; y++) {
    digitalWrite(row_pins[y], LOW);
    delay(1);
    for (int x = 0; x < COLUMNS; x++) {
      doWhenKeyIsPressed(x, y); // is key pressed? if so, do smth
    }

    digitalWrite(row_pins[y], HIGH);
  }

  // Keyboard.releaseAll(); //test1
  shouldKeyboardSleep(); // if keyboard want sleep keyboard yes sleep 
  turnOffKeysIfNeeded(); // :) only if they're pressed for longer than 3 seconds

  // standard delay for HID keyboard according to ch*tgpt
  delay(80);

  // don't touch until after tested
  delay(1000);
}

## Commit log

2025-07-02 fix highway issues
    [bom.csv, bottom.stl]
2025-07-05 change design
    [bottom.step, bottom.stl, full_keyboard.stl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]
2025-07-05 change design
    so much work!
    [bottom.step, hackpad_v2.kicad_pcb]
2025-07-06 change stuff
    [upper_ex.step]
2025-07-08 change pcb zip file
    [hackpad_v2-B_Cu.gbr, hackpad_v2-B_Mask.gbr, hackpad_v2-B_Paste.gbr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]
2025-07-09 fix bom's
    [bom.csv]
2025-07-09 add total to BOM
2025-11-23 improve journal and software
    [undercity v3.stl]
